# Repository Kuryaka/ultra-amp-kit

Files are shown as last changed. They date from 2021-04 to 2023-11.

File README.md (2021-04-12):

# Ultra Amp Conversion Kit

Fileset and instructions for the Ultra Amp Conversion Kit. Check https://github.com/Kuryaka/Daybreak-Cage-Library and https://github.com/Kuryaka/Pulsar-Cage-Library for the respective cages.

This free version does not have the battery tray, mag release lock, or fancier two-tone motor cover. I consider these parts non-essential and would like to keep access limited for the time being. If you are interested in purchasing the files or would like to tip me for my work, the full fileset is available on Etsy: https://www.etsy.com/listing/999885809/ultra-amp-full-fileset 

Please contact me at kurymakesthings(at)gmail(dot)com or on Discord (Kuryaka #0932) in the BAFT or /r/Nerf servers (or wherever you happen to find me!) if you have questions or  file format requests. 

<br />This work is licensed under a <a rel="license" href="http://creativecommons.org/licenses/by-nc-sa/4.0/">Creative Commons Attribution-NonCommercial-ShareAlike 4.0 International License</a>.

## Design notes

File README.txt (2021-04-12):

Recommended printing at 0.25mm resolution or finer for all parts. 

I found that PrusaSlicer settings have been tuned for better ID and OD tolerances, which means some parts have a looser-than-standard fit. 

The only part found to be significantly affected is the mag adapter plug, I have included an tighter-fitting version of it. 

Contact me via Etsy or via email at kurymakesthings@gmail.com for support.

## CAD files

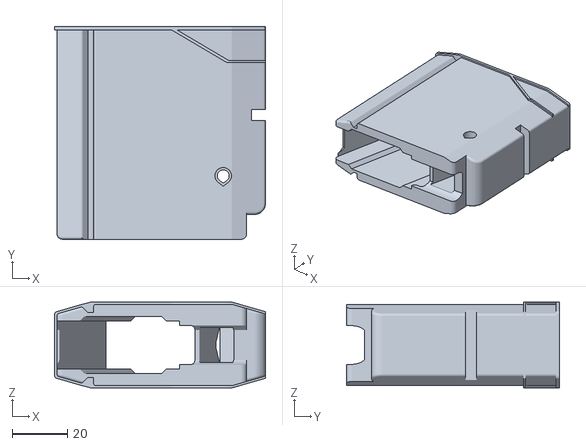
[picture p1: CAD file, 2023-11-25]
Mag Adapter/ANGLED Magwell v0.1.stl
76.4 x 77.0 x 31.1

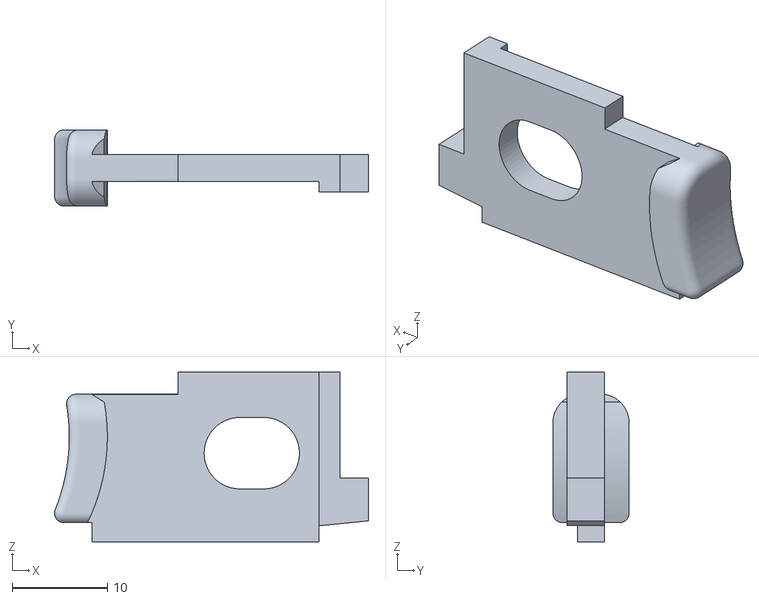
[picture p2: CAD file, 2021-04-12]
Rev Trigger.stl
33.0 x 8.00 x 17.8

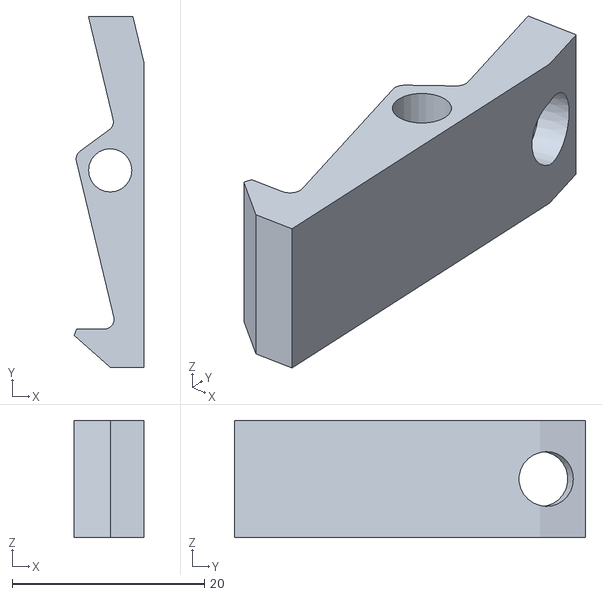
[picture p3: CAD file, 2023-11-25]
Mag Adapter/ANGLED Adapter Release v0.1.stl
7.25 x 36.5 x 12.2

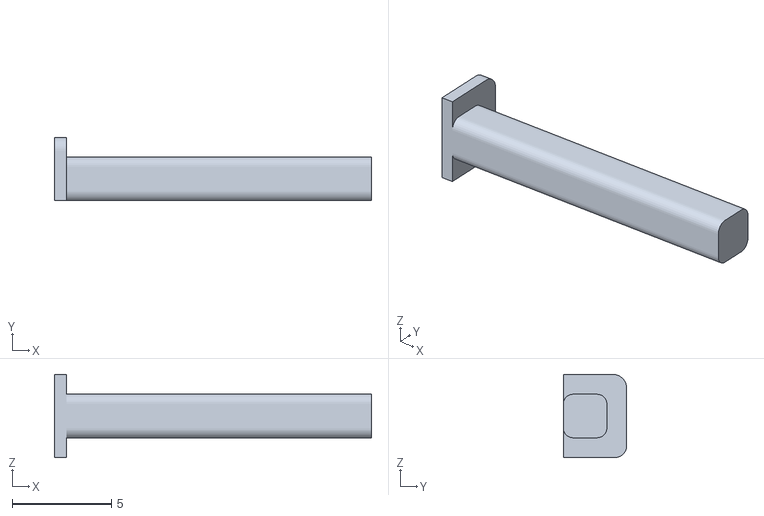
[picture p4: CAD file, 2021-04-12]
Switchplate Peg.stl
16.0 x 3.20 x 4.20

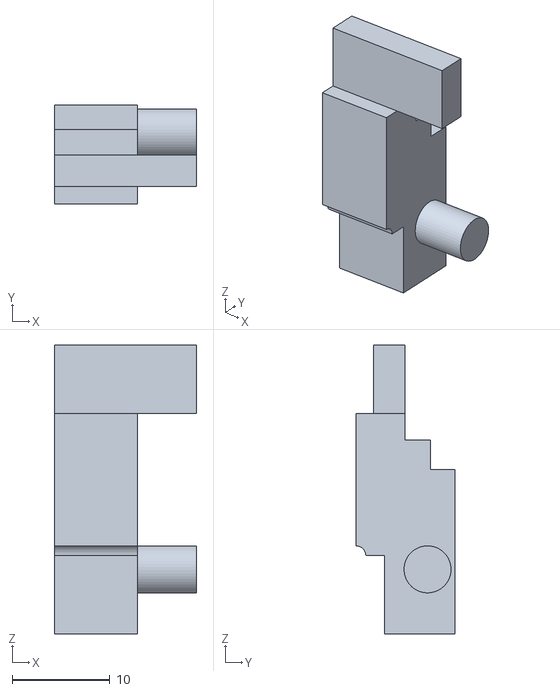
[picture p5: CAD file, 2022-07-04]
Mag Adapter/Mag Lock.stl
14.5 x 10.1 x 29.5

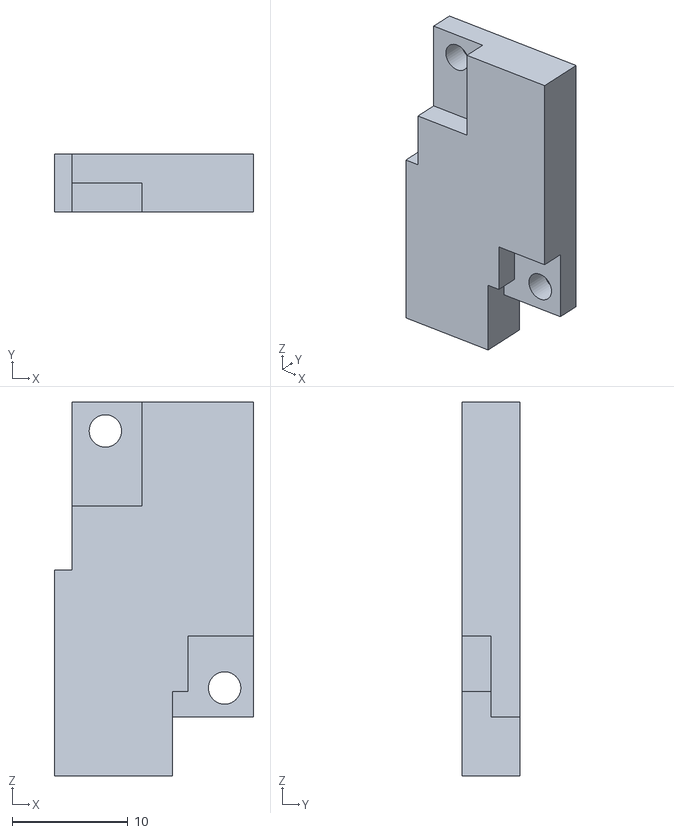
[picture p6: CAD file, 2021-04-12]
Switch Plate.stl
17.2 x 5.00 x 32.3

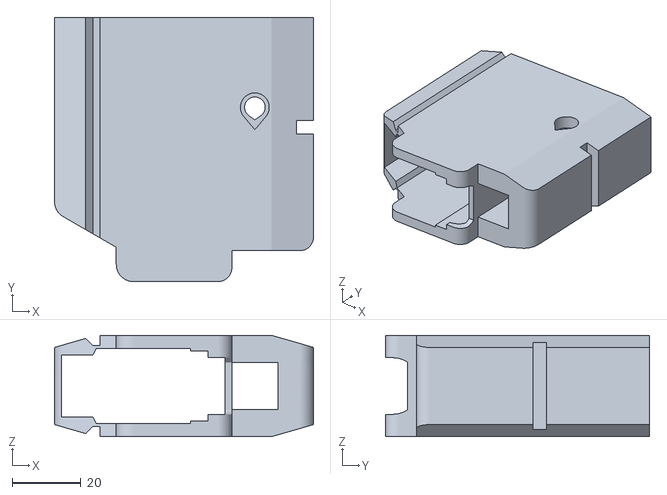
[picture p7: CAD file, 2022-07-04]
Mag Adapter/Generic Ultra Adapter Body.stl
75.5 x 77.0 x 29.5

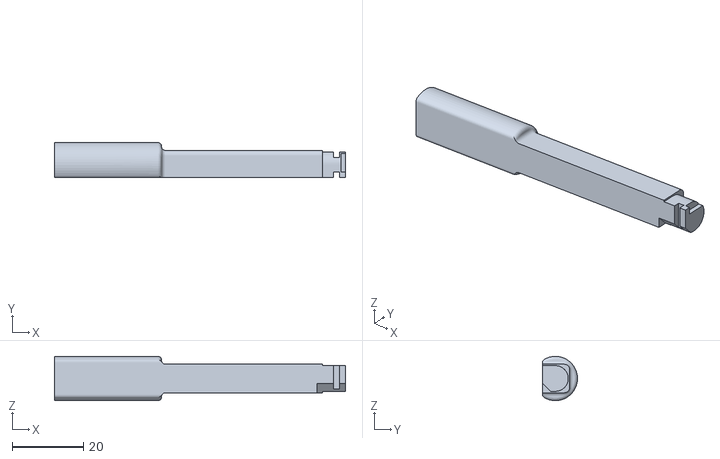
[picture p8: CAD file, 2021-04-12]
Pusher.stl
81.5 x 9.79 x 12.4

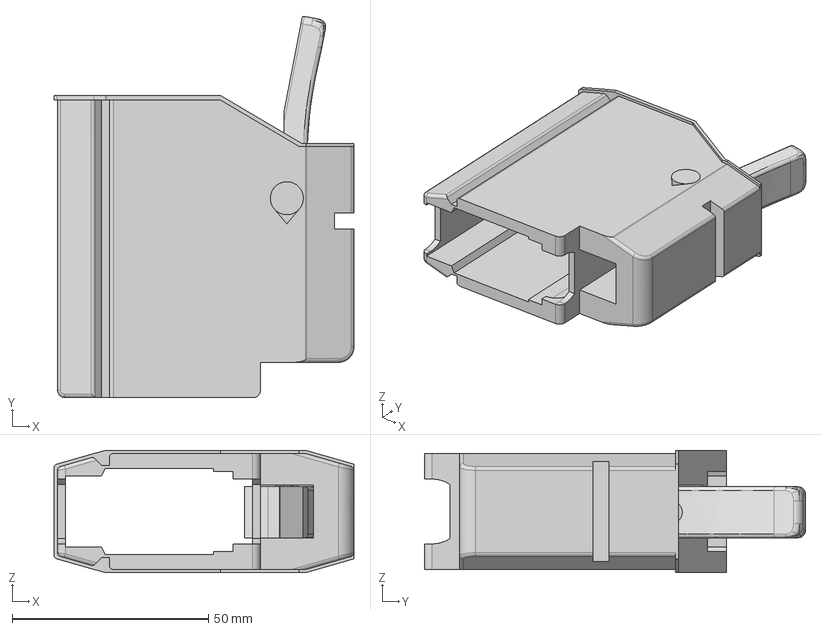
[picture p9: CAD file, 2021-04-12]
Mag Adapter/UltraAmpMag v3.step
76.4 x 97.1 x 31.1 mm
MagRelease
Nub x 2
Magwell

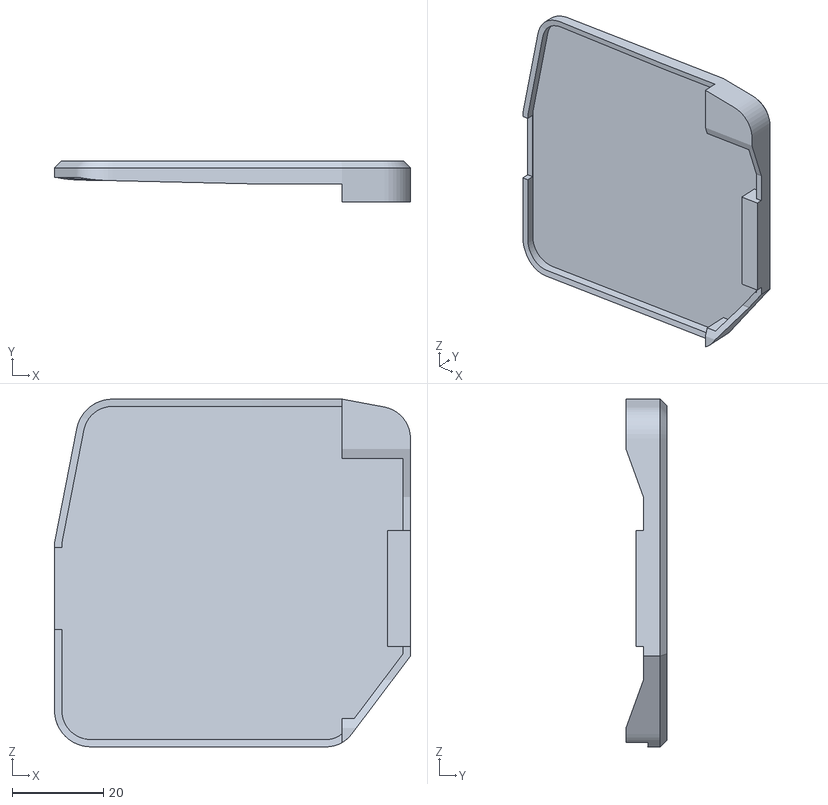
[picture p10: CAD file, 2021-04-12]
Cover Basic.stl
78.0 x 9.00 x 76.2

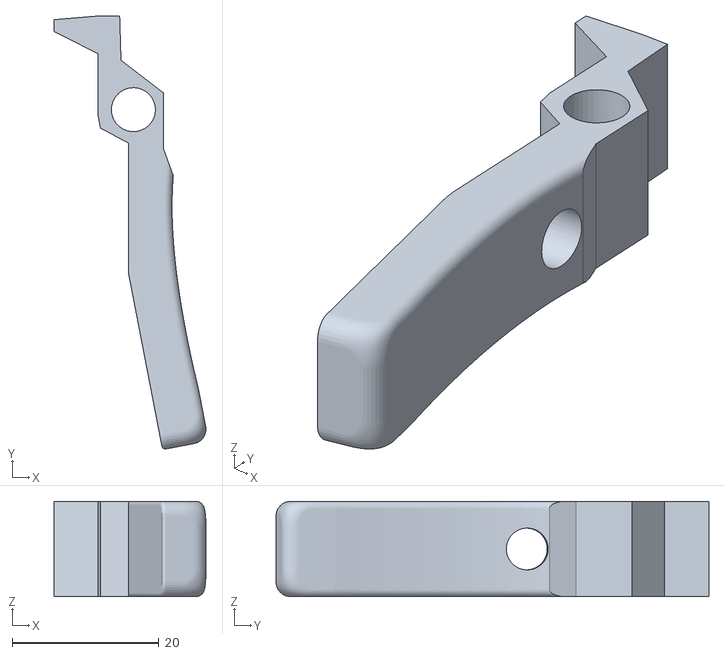
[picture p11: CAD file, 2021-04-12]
Mag Adapter/Adapter Release.stl
20.7 x 59.1 x 13.0

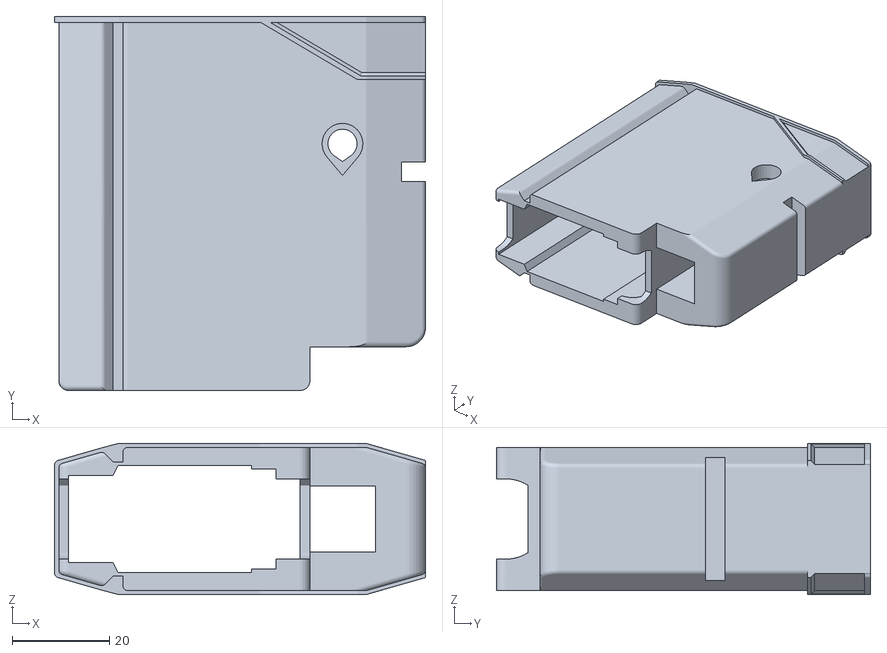
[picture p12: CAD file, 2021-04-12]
Mag Adapter/Adapter Body.stl
76.4 x 77.0 x 31.1

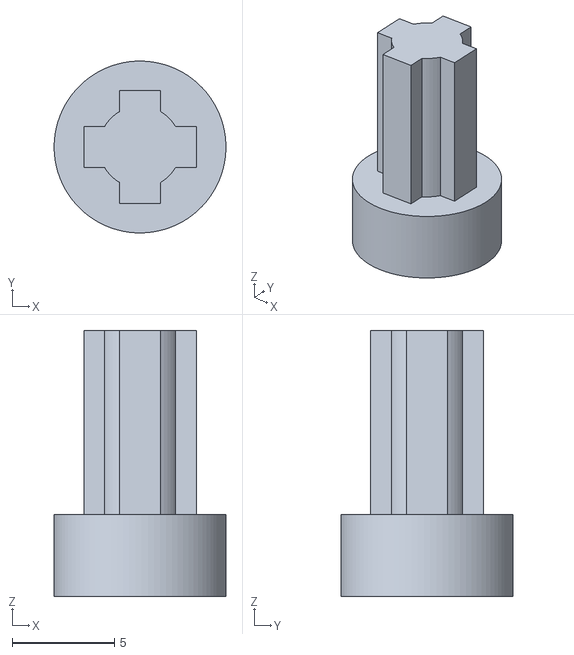
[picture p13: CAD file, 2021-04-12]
Mag Adapter/Adapter Peg Prusa.stl
8.40 x 8.40 x 13.0

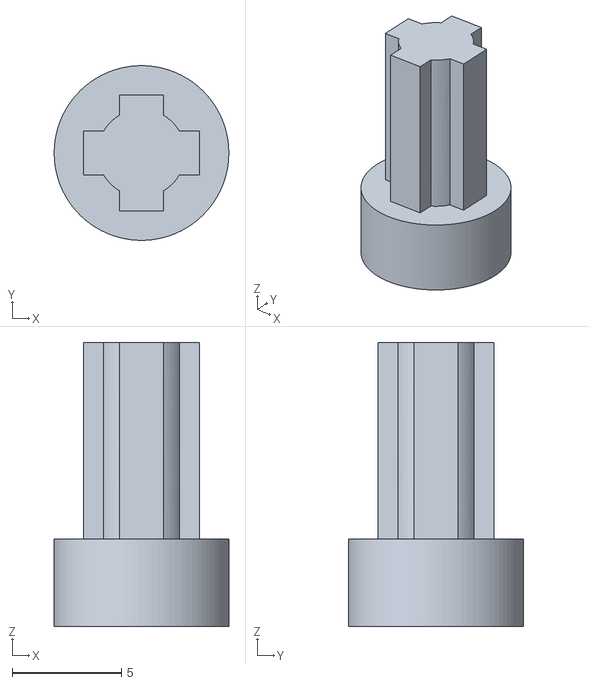
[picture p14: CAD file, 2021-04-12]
Mag Adapter/Adapter Peg.stl
8.00 x 7.99 x 13.0

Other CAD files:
Pusher_Old.stl

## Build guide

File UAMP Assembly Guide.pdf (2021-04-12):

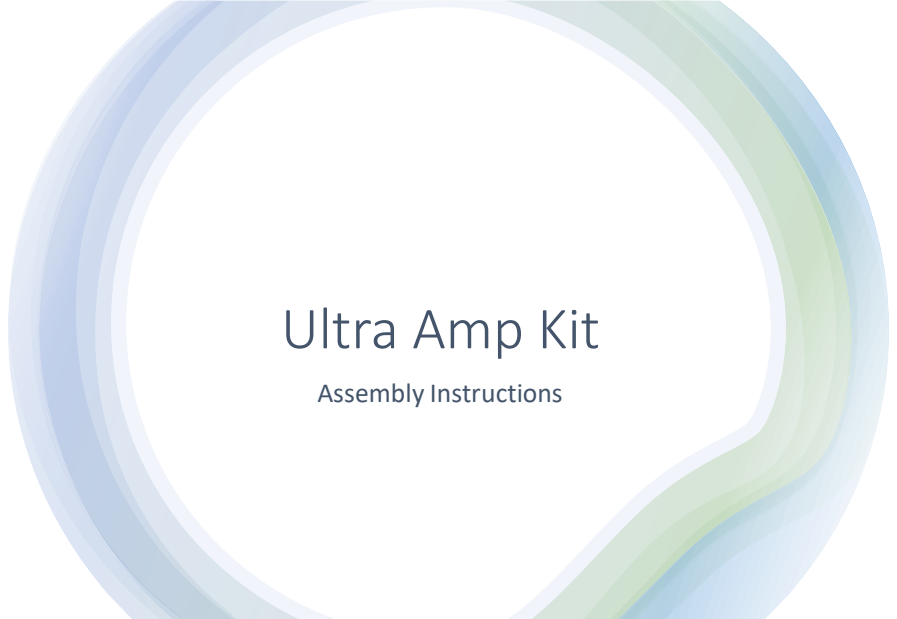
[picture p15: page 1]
Assembly Instructions

Ultra Amp Kit

# Parts List

- Flywheel Cage
- Adapter Body
- Adapter Peg (2)
- Adapter Release

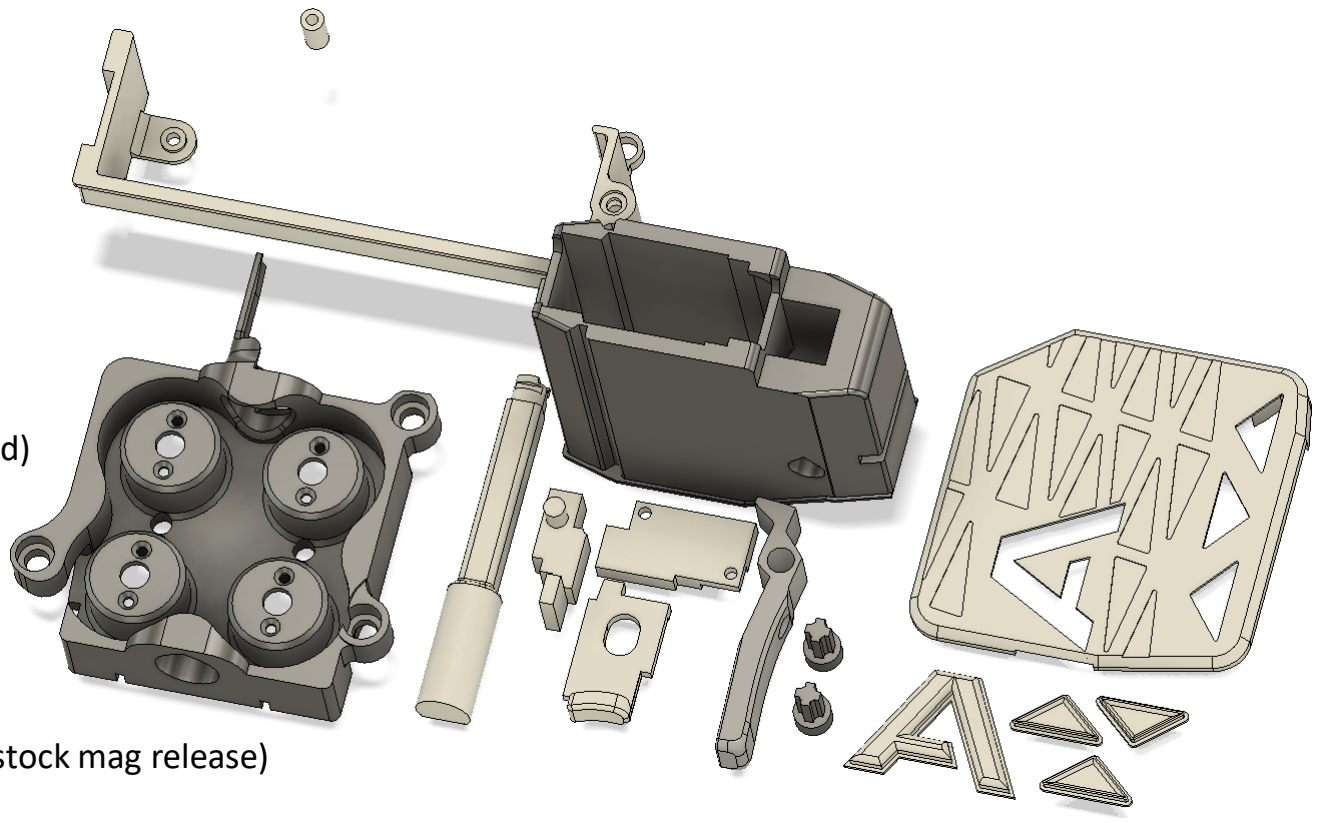
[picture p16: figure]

- Adapter Spring (dart head)
- Pusher
- Battery Tray
- Tray Peg
- Switch Plate
- Rev Trigger
- Mag Lock (replacement stock mag release)
- Motor Cover & Decorative Inserts (optional)

# Additional tools/materials required

## - Any sort of plastic-compatible glue: Superglue, epoxy, GOOP/E6000 - Diagonal cutter or pliers - Hot knife / Dremel / Drill and saw: For 2 stage motor cover

## - (2) 4-40 screws, 5/8” to 3/4“ in length (Included in kit) - Stock battery tray nut - Motor Screws - Wiring supplies, Omron V15 style switch, connectors of choice

# 2a. Shell Parts to Trim/Cut

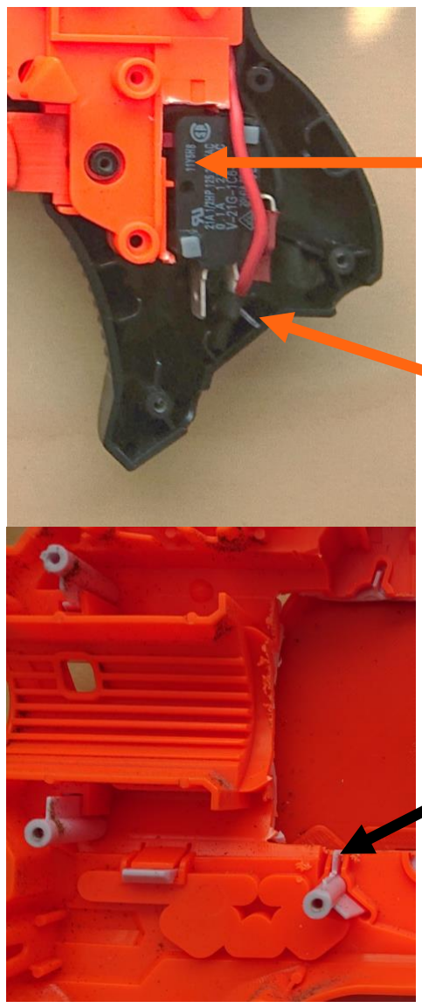
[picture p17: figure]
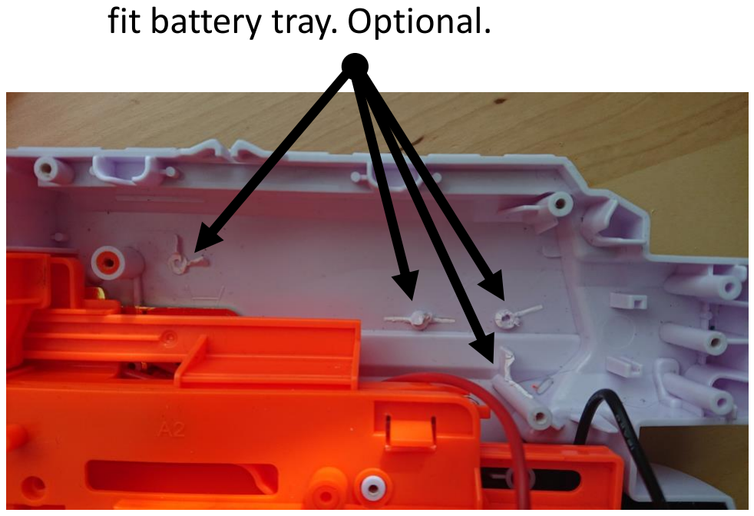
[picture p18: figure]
fit battery tray. Optional.

Pry off rear tab here to
fit switch lead.

Pry off this rib.

Trim the upper cover
here to fit switch.

Remove 3 pegs and remove 1 rib to

2a. Shell trimming cont.

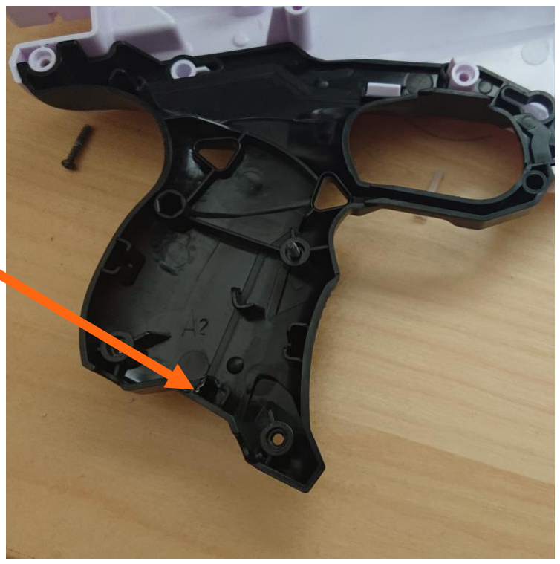
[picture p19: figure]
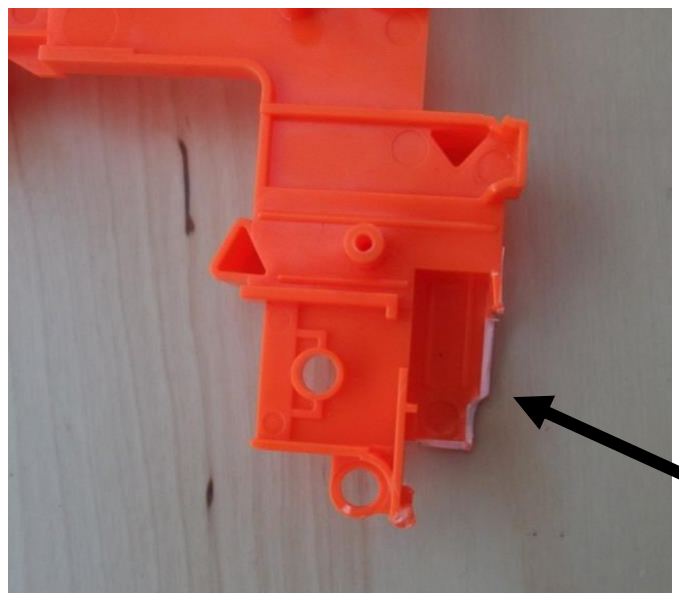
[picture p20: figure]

Use pliers / diagonal cutters to bend off the lower/right parts of the switch tray.

Remove the rear rib here
to fit the switch lead.

# 2b. Shell Cutting for 2 Stage Hurricanes

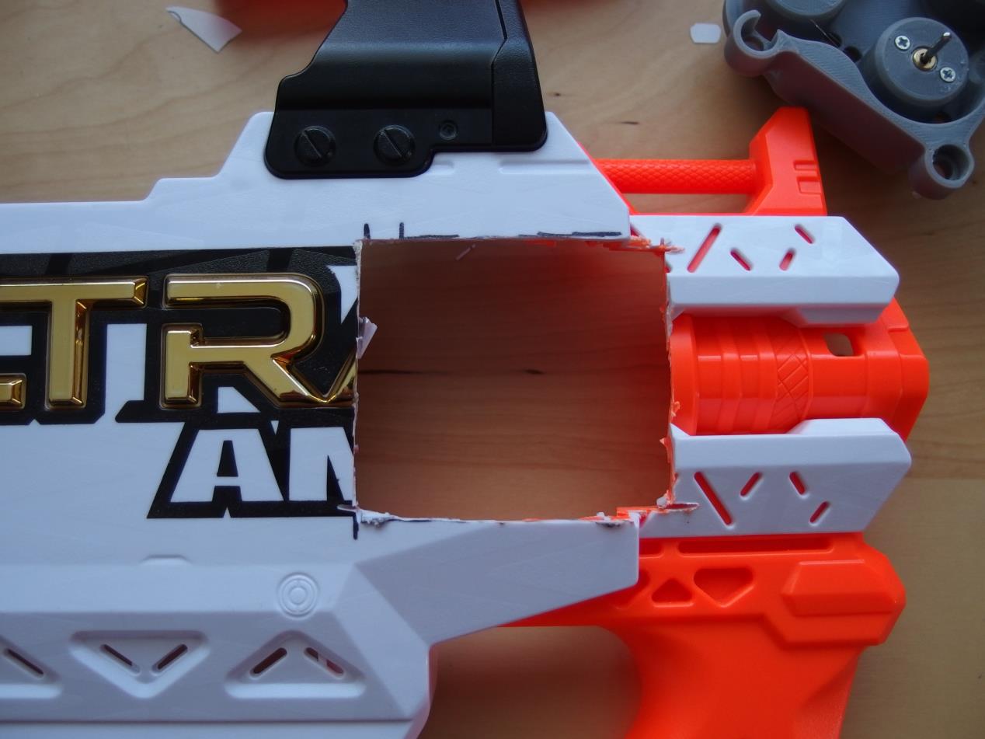
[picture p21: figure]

The hole should be rectangular. Rounded
corners are ok.

Top and bottom lines are bounded by the logo. I recommend cutting extra on the top to aid wire routing.

Rear of hole should be in the middle of the M.

Front cut should be near first sharp corner you see on the barrel deco.

Use a Dremel (pictured here), hot knife, hobby knife, and/or drill.

2b. 2 Stage Cuts cont.

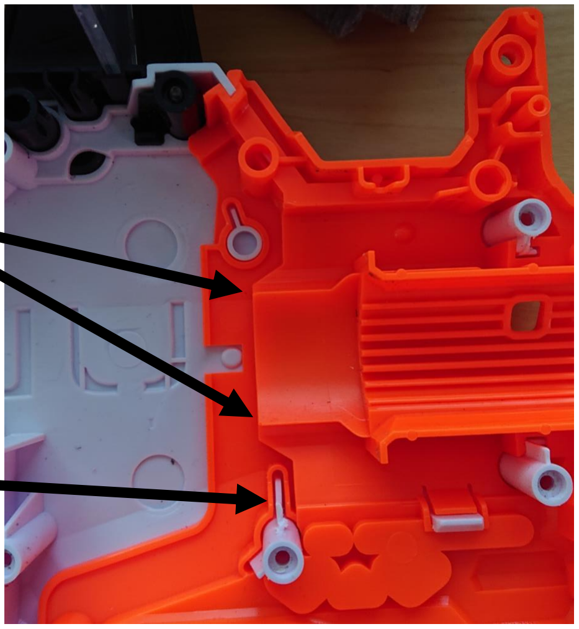
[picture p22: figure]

Clip 5mm off the rib here.

## File/Dremel about 2mm off these corners on the round barrel “guide.”

# 3a. Gluing Switch Plate and Battery Door

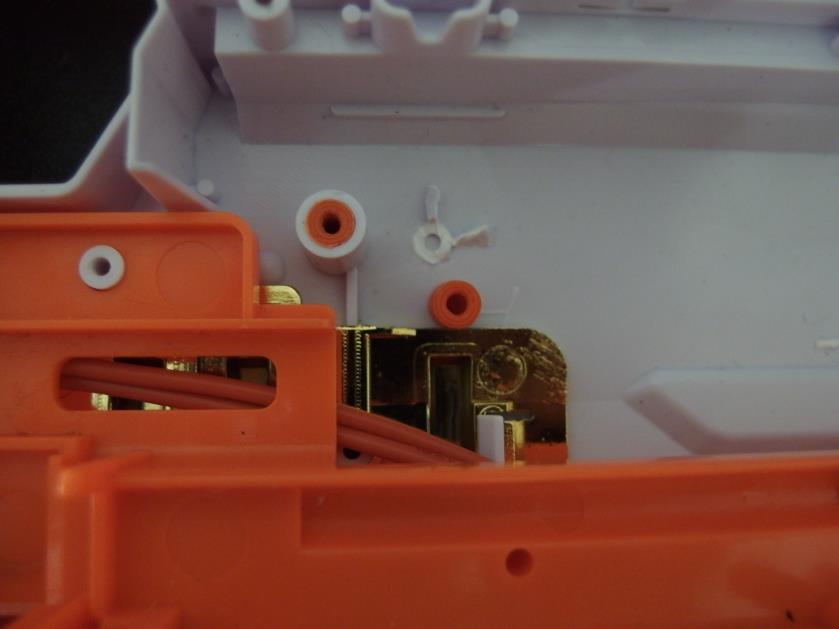
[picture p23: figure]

Take the Tray Peg (small cylinder) and press it into the large shell hole here. Use some glue if you’re worried about movement, or sand down if too large.

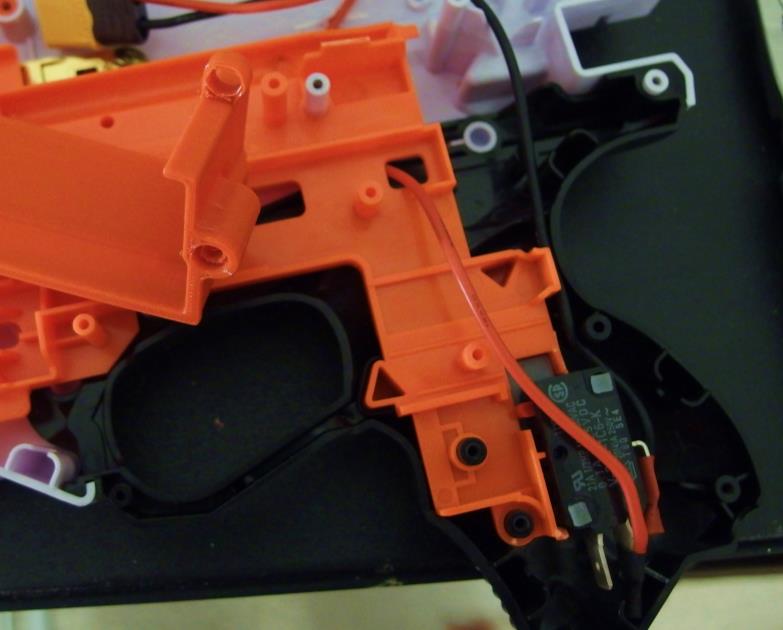
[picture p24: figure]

Apply glue of choice to the bottom of the Printed Switch Plate, press it into the stock switch plate.
Then install switch with printed peg + glue or the 4-40 screws included with the kit.

# 3b. Motor Cover Gluing

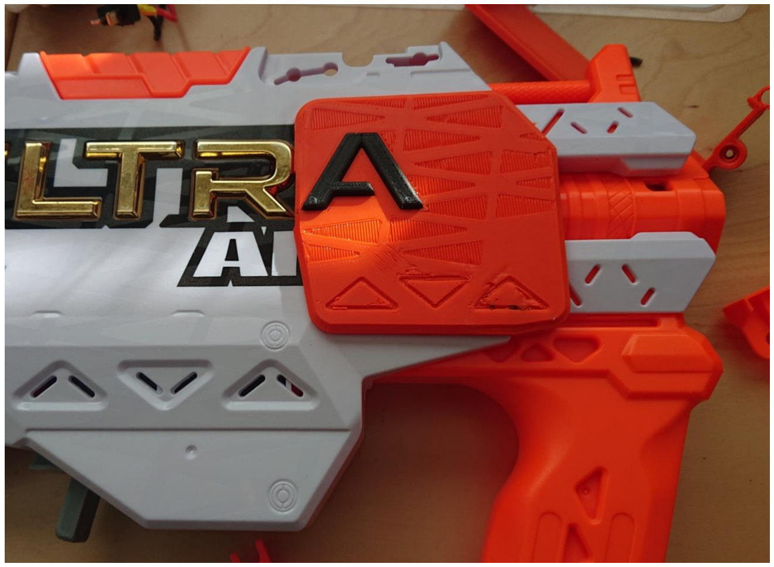
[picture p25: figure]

## Test Motor Cover fit and positioning, glue the Inserts if

applicable.

## I recommend testing that your motor wiring fits through the shell

as well.

## Apply glue of choice to rims of Motor Cover and press/clamp

until glue cures.

# 4a. Assorted Assembly

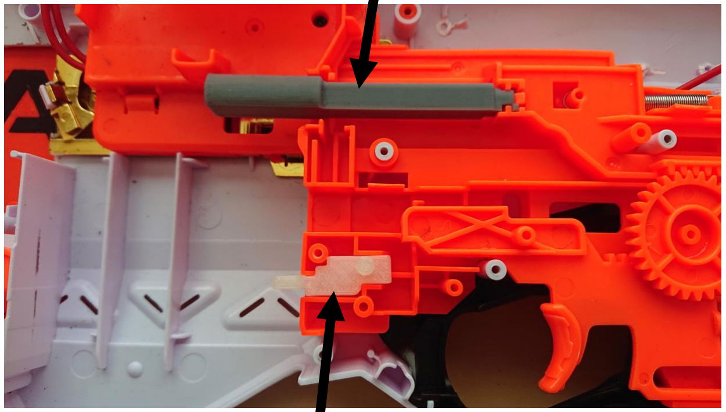
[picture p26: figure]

Replace the Mag Release to lock the adapter in place (optional). Put in the Rev Trigger (not pictured).

Replace the Pusher. Orient flat side down (toward magwell)

# 4b. Mag Adapter Assembly

- Insert dart head into Adapter Release.
- Insert Adapter Release into Adapter Body.

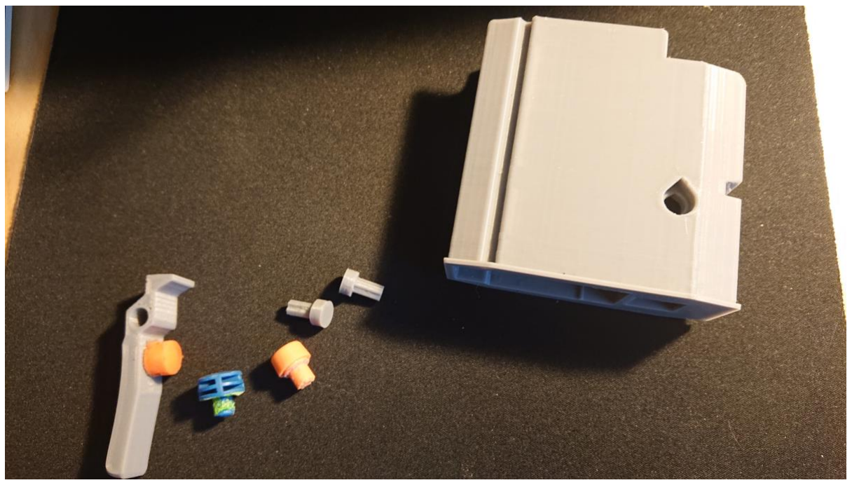
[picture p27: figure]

## - Insert Adapter Pegs, affix

with glue (or tape) of choice.

# 4c. Battery Tray Assembly

- Battery tray fits up to 1300-1500 mAh 3S batteries.

## - Remove the nut from stock battery tray and slide it into the printed

tray. Use a small amount of glue if needed and a screwdriver to help.

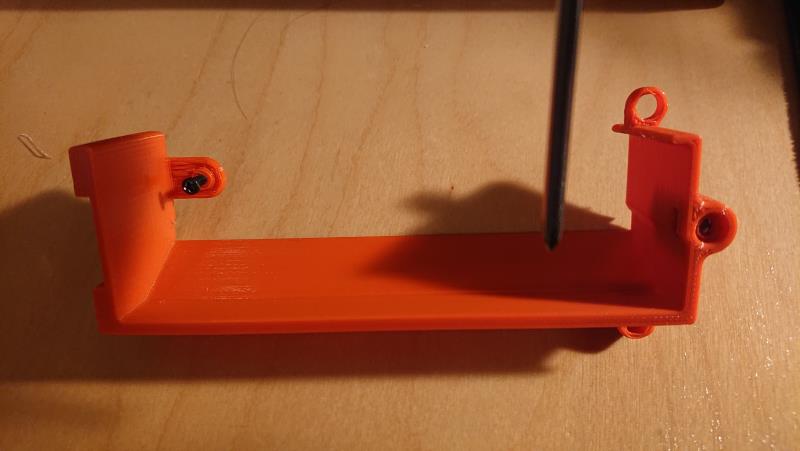
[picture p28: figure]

- Do your wiring, then assemble the battery tray with 2 shell screws.

# 5. Final Checks

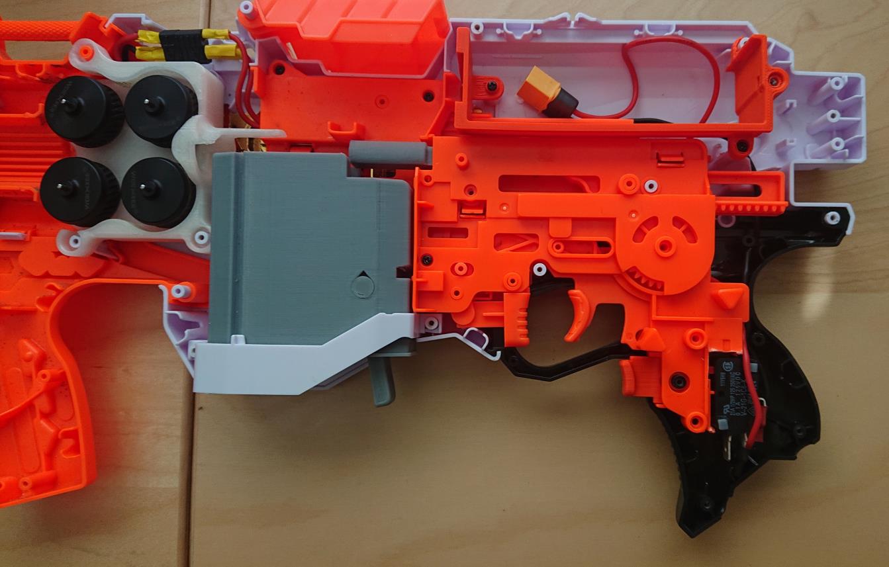
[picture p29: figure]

Check that everything fits together, your wiring is correct, and pusher works before fully closing the shell.

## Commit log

2021-04-12 File Upload
    [Adapter Body.stl, Adapter Peg Prusa.stl, Adapter Peg.stl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]
2022-07-04 File Updates
    Generic Ultra Adapter has more clearance.
    [Generic Ultra Adapter Body.stl, Mag Lock.stl]
